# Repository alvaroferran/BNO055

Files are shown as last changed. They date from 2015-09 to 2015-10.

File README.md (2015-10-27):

# BNO055
#### 9DOF Absolute orientation sensor

&nbsp;
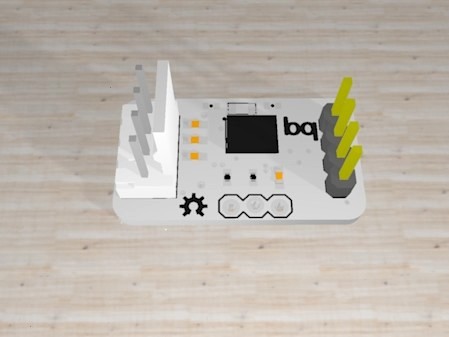
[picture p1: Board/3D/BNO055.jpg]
board


This repository contains the sensor board and a library for arduino. Both the board and the library are still under development and susceptible of improvement :)

#### BOARD

·The sensor works at 3.3V and can be used through UART or I2C by soldering the PS0 and PS1 pads below, as per the table below:

| PS1 | PS0 | Functionality  |
| --- |:---:| -----:|
| 0 | 0 | Standard/Fast I2C Interface|
| 0 | 1 | HID over I2C |
| 1 | 0 | UART Interface |
| 1 | 1 | Reserved |

In order to be used with a 5V level microcontroller a 5V-3.3V level shifter must be used.

&nbsp;
·It has two possible, hardware-defined I2C addresses, which are selectable through a solder pad, as in the following table:

| ID PAD | I2C Address | ID  |
| --- |:---:| -----:|
| Not soldered | 0x28 | A |
| Soldered | 0x29 | B  |

&nbsp;

·The "I2C" pad enables the sensor's 4.7k pullup resistors. This pad should only be soldered if there were no other pullup resistors on the bus.

&nbsp;

#### LIBRARY

· To install the library simply copy the folder "BNO055" into your folder "sketchbook/libraries/".

&nbsp;
· In the "examples" subfolder a cheatsheet sketch is available which demonstrates how to read different data.

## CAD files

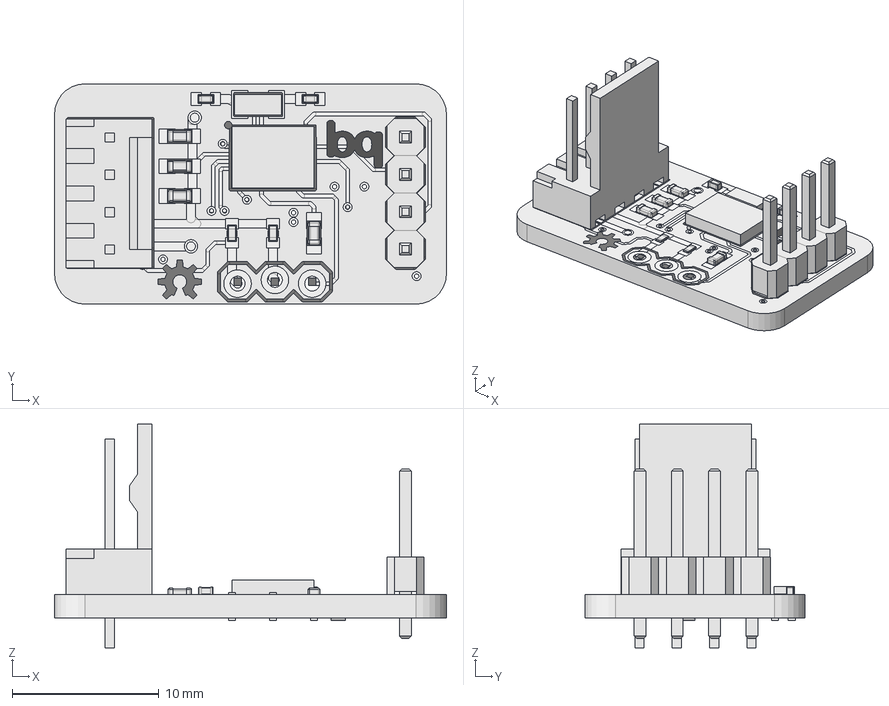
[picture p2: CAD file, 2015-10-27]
Board/3D/BNO055.fcstd
26.7 x 15.0 x 15.2 mm
Board
C1
C2
C3
C4
JP1
R2
R5
R6
R7
R1
R3
R4
JP2
Q1
C5
C6
U1
Top_1
Bottom_16
tPad_17
bPad_18
tPlace_21
bPlace_22
tDocu_51
bDocu_52

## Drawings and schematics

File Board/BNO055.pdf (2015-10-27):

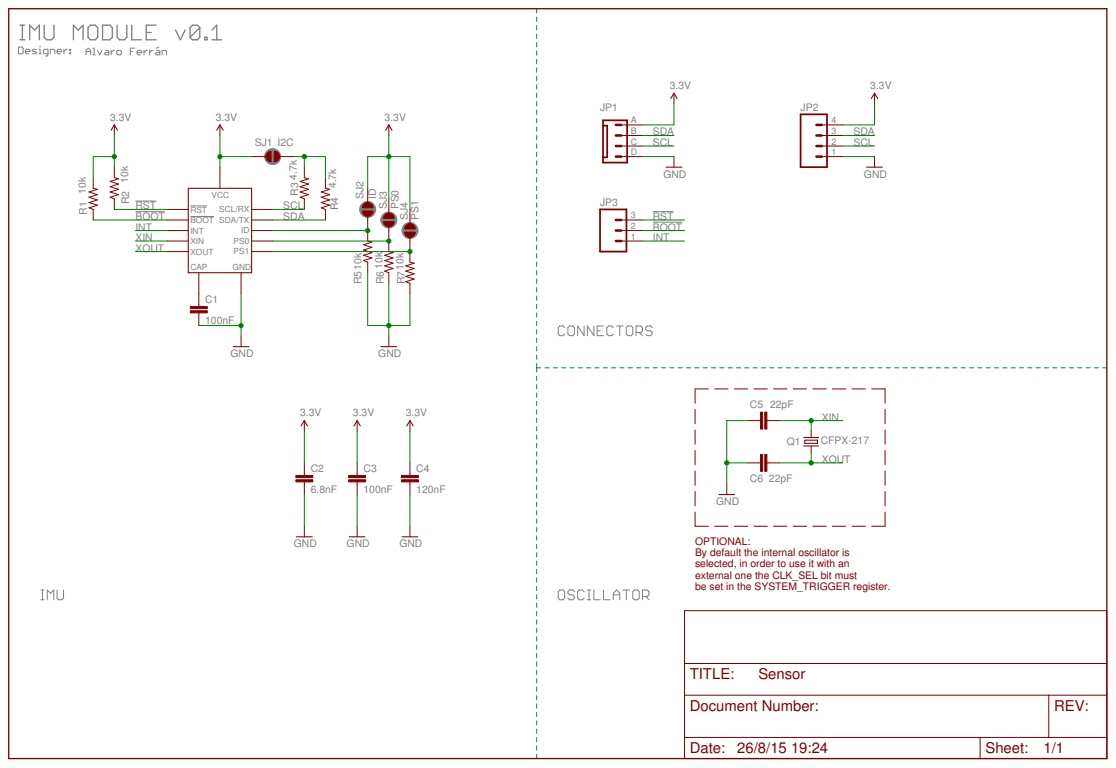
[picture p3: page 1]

OPTIONAL: By default the internal oscillator is
selected, in order to use it with an
external one the CLK_SEL bit must
be set in the SYSTEM_TRIGGER register.

Document Number: | REV:

Date: 26/8/15 19:24 | Sheet: 1/1

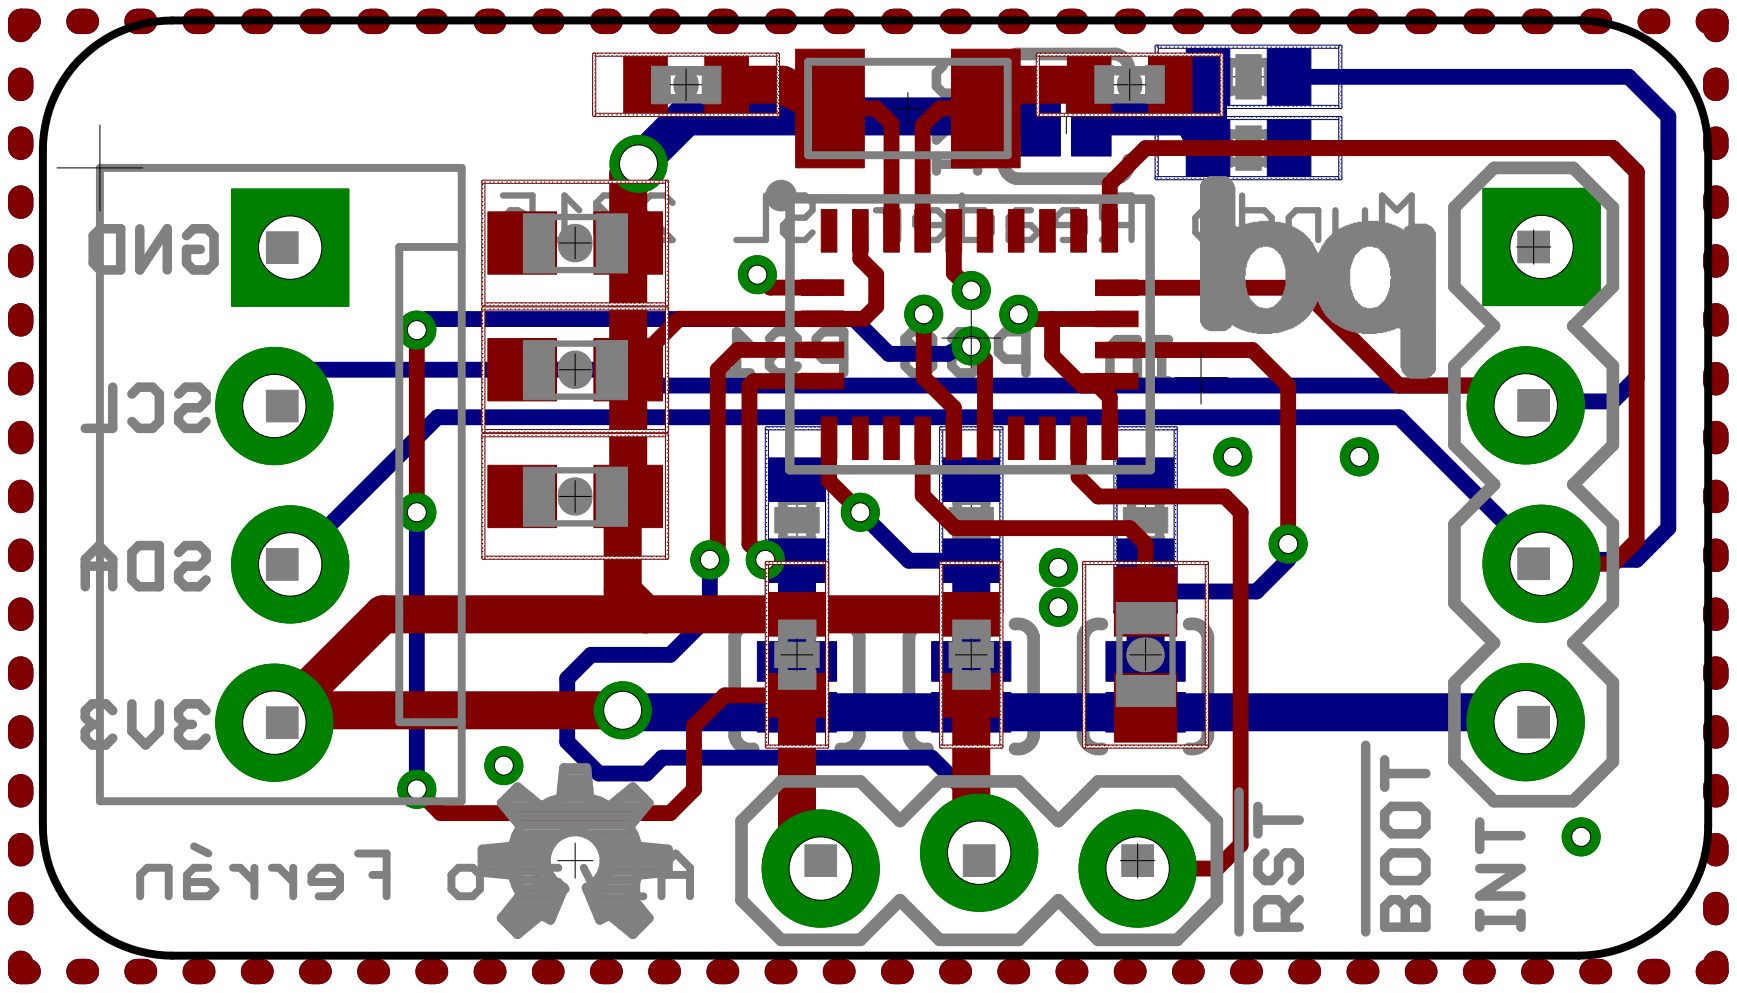
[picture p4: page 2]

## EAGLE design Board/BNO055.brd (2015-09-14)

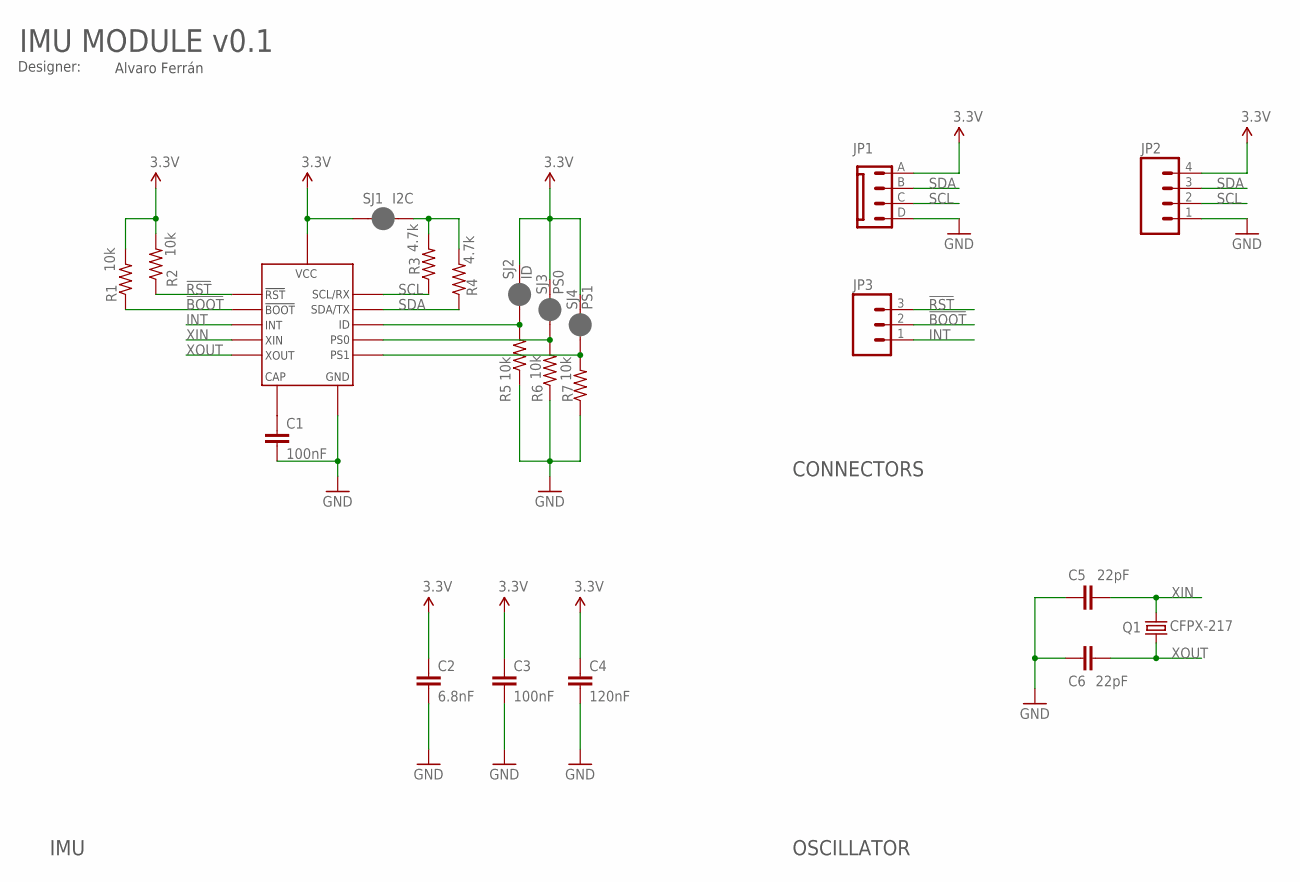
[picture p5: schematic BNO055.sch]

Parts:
C1, C3: 100nF; 0603-CAP
C2: 6.8nF; 0603-CAP
C4: 120nF; 0603-CAP
C5, C6: 22pF; 0402-CAP
JP1: MX-6410-04A
JP2: M04LOCK; 1X04_LOCK
JP3: M03LOCK; 1X03_LOCK
Q1: CFPX-217
R1, R2, R5, R6, R7: 10k; 0402-RES
R3, R4: 4.7k; 0402-RES
SJ1: I2C; PAD-JUMPER-2-NC_BY_PASTE_YES_SILK
SJ2: ID; PAD-JUMPER-2-NC_BY_PASTE_YES_SILK
SJ3: PS0; PAD-JUMPER-2-NC_BY_PASTE_YES_SILK
SJ4: PS1; PAD-JUMPER-2-NC_BY_PASTE_YES_SILK
U1: BNO055

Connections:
3.3V: C2.1, C3.1, C4.1, JP1.A, JP2.4, R1.2, R2.2, SJ1.2, SJ2.2, SJ3.2, SJ4.2, U1.3 (VCC), U1.28 (VCC)
!BOOT: JP3.2, R1.1, U1.4 (BOOT)
!RST: JP3.3, R2.1, U1.11 (RST)
GND: C1.2, C2.2, C3.2, C4.2, C5.1, C6.1, JP1.D, JP2.1, R5.1, R6.1, R7.1, U1.2 (GND), U1.10 (GND), U1.15 (GND), U1.16 (GND), U1.18 (GND), U1.25 (GND)
INT: JP3.1, U1.14 (INT)
unnamed: C1.1, U1.9 (CAP)
unnamed: R3.2, R4.2, SJ1.1
unnamed: R5.2, SJ2.1, U1.17 (ID)
unnamed: R6.2, SJ3.1, U1.6 (PS0)
unnamed: R7.2, SJ4.1, U1.5 (PS1)
SCL: JP1.C, JP2.2, R3.1, U1.19 (SCL/RX)
SDA: JP1.B, JP2.3, R4.1, U1.20 (SDA/TX)
XIN: C5.2, Q1.2, U1.27 (XIN)
XOUT: C6.2, Q1.1, U1.26 (XOUT)

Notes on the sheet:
IMU MODULE v0.1
Designer:
Alvaro Ferrán
CONNECTORS
OSCILLATOR
IMU

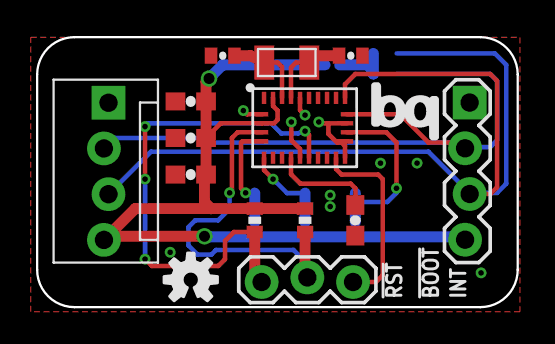
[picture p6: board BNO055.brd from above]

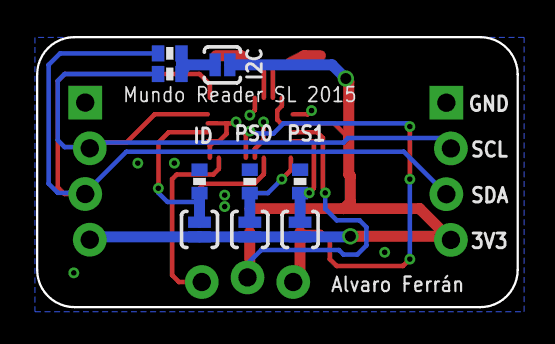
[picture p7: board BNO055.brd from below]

Board: 2 copper layers, 26.7 x 15.0 mm, 24 parts (9 on the bottom side), 14 nets.

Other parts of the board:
U$1: BQ_LOGO_MEDIUM
U$2: OSHW-LOGO-S

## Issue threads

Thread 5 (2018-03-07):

Clarifications on BNO055 and its calibration.

mrrobles09, 2018-03-07:
Good day sir alvaro ferran,

As I was strolling your code here for BNO055 I notice that in your set up for "initBNO055", your OPRMode was modified in CONFIGMODE then set your own values like e.g: Ascale = 2g and Abw =ABW_31_25Hz. After that, you set your OPRMode in NDOF Mode at the end of the routine which NDOF Mode is under fusion mode.

**Questions:**

1. How are you sure that the settled values before proceeding to NDOF Mode is not overwritten by its default sensor configuration?
2. How can you write your own settled offsets gathered in calibration routines and not be overwritten by the sensor in fusion mode?

I've set my calibration before and would like to use this values so that I won't have to recalibrate the sensor every time it is powered on and perhaps use the NDOF feature of BNO055 but this limitations makes my goal hard in getting the navigational position in my project.

Regards,
mrrobles09

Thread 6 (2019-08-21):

quaternion rotation backwards?

banyan-in-beijing, 2019-08-21:
Hi,
If I understand correctly:
1) The BNO055's linear acceleration output is in terms of the sensor's local frame XYZ axes, and the purpose of the readAbsAcc() function in BNO055.cpp is to rotate that linear acceleration vector into the absolute/global frame's XYZ axes.
2) The quaternion output from the BNO055 represents the rotation that must be applied to a fixed initial vector (0,0,0) in the global frame in order to obtain the sensor's current orientation.
3) When we "apply" a quaternion (q) rotation to a vector (v) by doing q*v*(q^-1) where (q^-1) is the conjugate of q, we rotate v by the rotation encoded in q.
4) a rotation specified by quaternion q is the opposite of the rotation specified by conjugate (q^-1). I.e. if v2 = q*v*(q^-1), then (q^-1)*v2*q would be equal to v.

If the above are correct, then I think the readAbsAcc() function rotates the linear acceleration vector not back into the global frame but instead doubles the offset from the global frame.
If I am reading the function correctly, it multiplies q*r*(q^-1) where r is the linear acceleration vector. However, since q is the rotation *from* the initial (0,0,0) vector in the global frame *to* the current orientation, not the rotation needed to get *to* the initial vector in the global frame *from* the current orientation, I think the readAbsAcc() function instead needs to multiply (q^-1)*r*q.

I'm not 100% sure of this; please let me know if there is an error in my reasoning.
Thanks!

P.S. Thank you for posting your code! It's helped me a lot in understanding how to use the BNO055.

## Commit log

2015-09-14 Board and library added
    [Sensor.brd, Sensor.sch]
2015-10-27 Freecad and PDF added
    [BNO055.brd, BNO055.fcstd, BNO055.sch]
2017-12-19 Calibration and self-test result functions added

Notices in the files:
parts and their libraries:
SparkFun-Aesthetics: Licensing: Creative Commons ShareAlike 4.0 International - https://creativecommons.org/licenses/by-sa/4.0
